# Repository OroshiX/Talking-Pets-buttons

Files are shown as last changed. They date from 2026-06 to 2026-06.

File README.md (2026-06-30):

# Talking Pet Buttons - écoute audio portable

Ce projet transforme un Arduino GIGA R1 WiFi en boîtier d'écoute pour boutons
enregistrables indépendants. Les boutons ne sont pas modifiés : le GIGA écoute
leur son avec un micro analogique, reconnaît chaque bouton par empreinte audio,
journalise les appuis sur une clé USB et envoie une notification `ntfy` via le
hotspot Android.

## Principe

```mermaid
flowchart LR
  A["Bouton enregistrable"] --> B["Son dans la pièce"]
  B --> C["Micro analogique A0"]
  C --> D["Arduino GIGA"]
  D --> E["Fingerprint audio"]
  E --> F["Log CSV sur clé USB"]
  E --> G["ntfy via hotspot Android"]
```

La V1 vise 6 à 8 boutons sur 2 tiles de yoga. Chaque bouton est placé dans un
support imprimé en 3D de type cylindre creux : une petite protubérance
intérieure suspendue porte le bouton, la zone sous le haut-parleur reste
dégagée, et les évents latéraux orientent le son vers le micro.

## Contenu du projet

- `src/main.cpp` : firmware PlatformIO pour Arduino GIGA R1 WiFi.
- `usb/config/` : exemples de fichiers à copier sur la clé USB.
- `hardware/button-riser.stl` : support 3D prêt pour PrusaSlicer.
- `hardware/button-riser.scad` : source paramétrique OpenSCAD du support.
- `docs/01-mise-en-route.md` : démarrage, firmware, USB, placement et calibration.
- `docs/02-liste-achats.md` : matériel recommandé pour la V1.
- `docs/03-agencement.md` : placement des tiles, du GIGA, du micro et des boutons.
- `docs/04-cablage.md` : câblage minimal du micro et de l'alimentation.
- `docs/05-schemas-branchement.md` : branchements micro, USB, alimentation et flux.
- `docs/06-cle-usb.md` : structure de la clé USB et formats des fichiers.
- `docs/07-calibration.md` : apprentissage des boutons avec les commandes série.
- `docs/08-tests.md` : checklist de validation avant usage quotidien.
- `hardware/01-support-3d.md` : support imprimable et réglages PrusaSlicer.
- `audio/01-audio.md` : notes sur les données audio utilisées par la V1.
- `docs/images/` : schémas SVG exportables/imprimables.

## Matériel V1

- Arduino GIGA R1 WiFi.
- Module micro analogique 3.3 V à gain réglable, type MAX4466.
- Clé USB-A FAT32.
- Batterie externe USB-C ou chargeur USB-C.
- Téléphone Android avec hotspot et application `ntfy`.
- 6 à 8 boutons enregistrables indépendants.
- 2 tiles de yoga emboîtables.
- Supports imprimés en 3D, un par bouton.
- Option : panneau de calibration avec 3 boutons NO et 6 LEDs binaires.

## Démarrage rapide

1. Copier `usb/config/buttons.csv`, `usb/config/settings.ini` et un
   `secrets.ini` basé sur `usb/config/secrets.example.ini` à la racine d'une
   clé USB FAT32, en gardant les dossiers.
2. Brancher le micro :
   - `VCC` vers `3V3` ;
   - `GND` vers `GND` ;
   - `OUT` vers `A0`.
3. Brancher la clé USB dans le port USB-A du GIGA.
4. Alimenter le GIGA en USB-C.
5. Compiler et téléverser avec PlatformIO.
6. Ouvrir le moniteur série à `115200` bauds, ou utiliser
   `pio device monitor -b 115200`.
7. Lancer `cal A1 12`, puis presser le bouton A1 12 fois.
8. Répéter pour chaque bouton.
9. Lancer `testntfy`, puis vérifier l'application Android.

## Commandes série

```text
help              affiche les commandes
list              affiche les boutons et templates chargés
status            affiche USB, Wi-Fi, heure, bruit, sélection et calibration
usb               monte ou remonte la clé USB maintenant
reload            recharge la config et les templates depuis la clé USB
select N          règle la sélection du panneau ; 0 éteint les LEDs binaires
ledtest N         affiche une valeur brute 0..63 sur les LEDs binaires
wifi              connecte le GIGA au Wi-Fi configuré maintenant
ntp               synchronise l'heure NTP maintenant
cal A1 [12]       apprend les prochains appuis pour le slot A1
cancel            annule une calibration active
testntfy          envoie une notification de test
```

Le panneau de calibration optionnel utilise `D22` pour `CAL`, `D23` pour `+`,
`D24` pour `-`, et `D25` à `D30` pour les 6 LEDs binaires. L'état `000000`
signifie qu'aucun bouton animal n'est sélectionné.

## Important

- Le GIGA ne fait pas de reconnaissance vocale générale. Il compare des sons de
  boutons déjà appris.
- Si tu réenregistres le message d'un bouton, il faut refaire sa calibration.
- Si tu changes fortement la position du micro ou des boutons, refais au moins
  un test de précision.
- Les notifications sont mises en attente dans `/queue/ntfy-pending.jsonl` si le
  hotspot est indisponible.

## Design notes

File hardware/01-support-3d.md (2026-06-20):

# Support 3D pour bouton

`button-riser.stl` est le fichier prêt à ouvrir dans PrusaSlicer. Les unités
sont en millimètres.

`button-riser.scad` est la source paramétrique OpenSCAD si tu veux changer le
diamètre du bouton ou la hauteur du support. Le design est un cylindre creux :
le bouton repose sur une petite protubérance intérieure suspendue, et la chambre
centrale reste dégagée sous le haut-parleur.

`generate_button_riser_stl.py` génère le STL sans dépendance externe :

```sh
python3 hardware/generate_button_riser_stl.py
```

Orientation :

- la petite flèche en relief pointe vers le micro ;
- le grand évent latéral doit aussi être orienté vers le micro ;
- le bouton se pose par-dessus, sur la petite protubérance intérieure ;
- imprimer à plat, sans rotation.

Réglages de départ PrusaSlicer :

- PLA ou PETG ;
- hauteur de couche 0,20 mm ;
- 3 périmètres ;
- 15 à 20% d'infill ;
- supports désactivés pour un premier essai.

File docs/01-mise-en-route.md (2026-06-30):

# Mise en route

## 1. Préparer le firmware

Dans CLion, VS Code ou un terminal PlatformIO :

```sh
pio run
pio run --target upload
```

La cible attendue est `giga_r1_m7` dans `platformio.ini`.

Pour éviter de retaper la vitesse du moniteur série à chaque fois, garder aussi
la ligne suivante dans `platformio.ini` :

```ini
monitor_speed = 115200
```

Ouvrir ensuite le moniteur série à `115200` bauds. Au démarrage, le GIGA affiche
la liste des commandes :

```text
help
list
status
usb
reload
select 0
ledtest 63
wifi
ntp
cal A1 12
cancel
testntfy
```

Ces commandes sont à taper dans le moniteur série connecté au GIGA, pas dans le
terminal de l'ordinateur. Elles sont l'interface de diagnostic et de calibration
du firmware.

`115200` bauds est la vitesse de communication entre l'ordinateur et le GIGA pour
ce moniteur série. Dans Arduino IDE, choisir `115200 baud` dans le menu du
moniteur série. Avec PlatformIO en terminal, utiliser :

```sh
pio device monitor -b 115200
```

## 2. Préparer la clé USB

Formater une clé USB-A en FAT32, puis copier la structure suivante :

```text
/config/buttons.csv
/config/settings.ini
/config/secrets.ini
/templates/
/logs/
/queue/
/captures/
```

Les exemples du dépôt sont dans `usb/config/`.

`secrets.ini` n'est pas versionné, car il contient le mot de passe hotspot et le
topic `ntfy`.

## 3. Brancher le micro

```text
Module micro analogique        Arduino GIGA

VCC  ------------------------>  3V3
GND  ------------------------>  GND
OUT  ------------------------>  A0
```

Utiliser `3V3`, pas `5V`. Garder les fils du micro courts : 30 cm maximum est un
bon objectif.

## 4. Placer le setup

Lire `docs/03-agencement.md`, puis installer :

- le GIGA derrière les tiles, hors zone de pattes ;
- le micro à 25-35 cm de haut, pointé vers le centre des boutons ;
- les boutons posés dans leurs supports 3D, avec l'évent le plus large orienté
  vers le micro.

## 5. Calibrer les boutons

Deux méthodes sont possibles : les commandes série ci-dessous, ou le panneau
physique décrit dans `docs/07-calibration.md`.

Pour chaque slot :

```text
cal A1 12
```

Presser ensuite le bouton A1 12 fois, depuis sa vraie position sur la tile.

Répéter :

```text
cal A2 12
cal A3 12
cal A4 12
cal B1 12
cal B2 12
```

Le GIGA crée les fichiers :

```text
/templates/A1.tpl
/templates/A2.tpl
...
```

## 6. Tester

Commandes utiles :

```text
status
list
usb
select 0
ledtest 63
wifi
ntp
testntfy
```

Puis presser chaque bouton 20 fois en conditions réelles. La checklist complète
est dans `docs/08-tests.md`.

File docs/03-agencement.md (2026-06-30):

# Agencement physique

## Vue de dessus

Agencement audio

```text
Mur / zone hors passage animal

        [Boîtier GIGA]
             |
        mât micro 25-35 cm haut
             v
        micro pointe vers centre des boutons

+--------------------+--------------------+
| Tile A             | Tile B             |
|                    |                    |
|  A1      A2        |  B1      B2        |
|                    |                    |
|  A3      A4        |  B3      B4        |
|                    |                    |
+--------------------+--------------------+

Animal arrive plutôt par le bas / côté ouvert.
```

## Positions recommandées

- Boîtier GIGA : derrière les tiles, hors zone de pattes.
- Micro : environ 20 cm derrière le bord arrière des tiles.
- Hauteur micro : 25 à 35 cm au-dessus du sol.
- Orientation micro : pointe vers le centre géométrique des boutons.
- Distance micro-boutons : 35 à 80 cm si possible, moins de 1 m en V1.
- Boutons : 8 à 12 cm d'espace entre eux.

## Orientation des boutons

Chaque bouton doit être posé dans un support imprimé. Il repose sur une petite
protubérance intérieure du cylindre ; cette tablette ne descend pas jusqu'en
bas, donc la chambre centrale reste ouverte sous le haut-parleur. L'évent le
plus large du support est orienté vers le micro.

```text
Micro
  ^
  |
  |       évent large du support
  |              ^
  |              |
+---+        +--------+
| A1|        |   A2   |
+---+        +--------+
```

## Routine de voyage

Pour déplacer le setup :

1. laisser les boutons dans leurs supports ;
2. empiler les tiles ;
3. garder le micro fixe au boîtier ou à un petit mât pliable ;
4. brancher le GIGA à une batterie externe ;
5. activer le hotspot Android ;
6. si tu vérifies depuis l'ordinateur, lancer `wifi` puis `ntp`, ou attendre
   `Wi-Fi connected` et `NTP synced` si `auto_ntp=true`.

Si le placement change beaucoup, lancer au minimum un test de 5 pressions par
bouton. Si la confiance baisse nettement, refaire la calibration.

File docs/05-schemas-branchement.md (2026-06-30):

# Schémas de branchement et flux

## Vue générale

Schéma de branchement global

Ce schéma montre les branchements réels à faire. Le point important : les piles
des boutons enregistrables restent dans les boutons. Elles ne servent pas à
alimenter l'Arduino. Le GIGA est alimenté séparément par USB-C, idéalement avec
une batterie externe ou un chargeur USB-C stable.

```text
Batterie externe USB-C 5 V
        |
        v
Arduino GIGA R1 WiFi
   | USB-A  -> clé USB FAT32
   | 3V3    -> VCC du micro MAX4466
   | A0     -> OUT / AO du micro MAX4466
   | GND    -> GND du micro MAX4466
   | Wi-Fi  -> hotspot Android -> ntfy
   | D22    -> bouton CAL vers GND
   | D23    -> bouton + vers GND
   | D24    -> bouton - vers GND
   | D25-D30 -> 6 LEDs binaires avec résistances 1 kΩ

Boutons enregistrables
   | piles internes
   | aucun fil vers le GIGA
   v
son capté par le micro
```

Agencement audio

```text
Téléphone Android hotspot ))) Wi-Fi ))) Arduino GIGA ))) HTTPS ))) ntfy
                                             |
USB-C power bank ----------------------------+
                                             |
Clé USB FAT32 ---- USB-A GIGA ---------------+
                                             |
Micro analogique ---- A0 / 3V3 / GND --------+
```

Le GIGA ne touche pas aux boutons. Les boutons restent indépendants, avec leur
pile et leur propre message enregistré. La seule liaison entre les boutons et le
GIGA est acoustique : le bouton joue son message, puis le micro le capte.

## Branchement micro

Branchement micro

```text
Module micro analogique        Arduino GIGA

VCC  ------------------------>  3V3
GND  ------------------------>  GND
OUT  ------------------------>  A0
```

Règles :

- alimenter le micro en `3V3` ;
- ne jamais envoyer de `5V` sur `A0` ;
- garder les fils courts ;
- régler le gain pour qu'un bouton fort ne sature pas le signal.

Le micro n'a pas besoin de pile séparée : il est alimenté par le `3V3` du GIGA.

## Panneau de calibration optionnel

Le panneau de calibration permet de choisir et calibrer un bouton animal sans
ordinateur. Les commandes série restent disponibles.

```text
Boutons électriques NO         Arduino GIGA

CAL borne 1 ----------------->  D22
CAL borne 2 ----------------->  GND

+ borne 1 ------------------->  D23
+ borne 2 ------------------->  GND

- borne 1 ------------------->  D24
- borne 2 ------------------->  GND
```

Ces boutons utilisent `INPUT_PULLUP`, donc aucune résistance externe n'est
nécessaire pour eux.

```text
LEDs binaires                 Arduino GIGA

bit 1  LED + résistance 1 kΩ  D25
bit 2  LED + résistance 1 kΩ  D26
bit 4  LED + résistance 1 kΩ  D27
bit 8  LED + résistance 1 kΩ  D28
bit 16 LED + résistance 1 kΩ  D29
bit 32 LED + résistance 1 kΩ  D30
```

Ordre de lecture recommandé de gauche à droite : `32 16 8 4 2 1`, donc
`D30 D29 D28 D27 D26 D25`. L'état `000000` signifie qu'aucun bouton animal n'est
sélectionné.

## Support audio du bouton

Support bouton

Objectif : que le bouton repose dans un cylindre creux, sur une petite
protubérance intérieure suspendue, pendant que la zone sous le haut-parleur
reste ouverte au lieu d'être absorbée par la tile de yoga.

Le support recommandé :

- parois droites ;
- cylindre creux simple, sans plancher central ;
- protubérance intérieure à 7 mm de haut environ ;
- protubérance de quelques millimètres d'épaisseur et de profondeur ;
- cette protubérance ne descend pas jusqu'en bas du cylindre ;
- chambre centrale ouverte sous le haut-parleur ;
- 3 à 4 évents latéraux connectés à cette chambre d'air ;
- un évent plus large orienté vers le micro ;
- Velcro ou patins caoutchouc dessous.

Le fichier prêt pour PrusaSlicer est :

```text
hardware/button-riser.stl
```

La source modifiable reste :

```text
hardware/button-riser.scad
```

## Flux logiciel

```mermaid
flowchart LR
  A["Bouton pressé"] --> B["Son capté par A0"]
  B --> C["Seuil adaptatif + pré-roll"]
  C --> D["Capture 1,5 s"]
  D --> E["Fingerprint audio"]
  E --> F["Comparaison templates"]
  F --> G{"Confiance >= 0,75 ?"}
  G -->|oui| H["Log CSV + ntfy"]
  G -->|non| I["Log unknown"]
```

Si le Wi-Fi ou le hotspot n'est pas disponible, l'événement reconnu est ajouté à :

```text
/queue/ntfy-pending.jsonl
```

Le GIGA renvoie cette file au retour du Wi-Fi si `auto_queue_flush=true`. En
mode diagnostic, garder `auto_queue_flush=false` et tester d'abord `wifi`, `ntp`,
puis `testntfy`.

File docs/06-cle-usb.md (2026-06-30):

# Clé USB

## Structure

```text
/config/buttons.csv
/config/settings.ini
/config/secrets.ini
/templates/A1.tpl
/templates/A2.tpl
/logs/YYYY-MM-DD.csv
/logs/unsynced.csv
/queue/ntfy-pending.jsonl
/captures/
```

Le firmware crée les dossiers manquants au démarrage, mais il est plus simple de
copier la structure du dossier `usb/` du dépôt.

## `/config/buttons.csv`

```csv
slot,word,ntfy_label
A1,manger,Manger
A2,eau,Eau
A3,jouer,Jouer
A4,dehors,Dehors
B1,dedans,Dedans
B2,calin,Câlin
```

- `slot` : position physique sur les tiles.
- `word` : identifiant court dans les logs.
- `ntfy_label` : texte humain dans les notifications.

## `/config/secrets.ini`

Créer ce fichier à partir de `secrets.example.ini`.

```ini
wifi_ssid=NomDuHotspot
wifi_pass=MotDePasseHotspot
ntfy_host=ntfy.sh
ntfy_topic=topic-prive-long
ntfy_token=
ntfy_tls=true
timezone_offset_minutes=120
```

Utiliser un topic `ntfy` long et difficile à deviner. Ne pas versionner
`secrets.ini`.

## `/config/settings.ini`

```ini
confidence_threshold=0.75
match_distance_at_zero=0.12
min_trigger_abs=650
trigger_multiplier=4.0
capture_ms=1500
cooldown_ms=800
calibration_samples=12
auto_ntp=false
auto_queue_flush=false
```

Ces valeurs sont rechargeables avec la commande série :

```text
reload
```

Si `status` affiche `USB=missing`, la commande série `usb` tente de remonter la
clé sans recharger toute la configuration. `reload` tente aussi de remonter la
clé, puis recharge `buttons.csv`, `settings.ini`, `secrets.ini` et les templates.

`auto_ntp=false` empêche la synchronisation NTP automatique au démarrage. C'est
le mode recommandé tant que la connexion réseau est en diagnostic : le GIGA
reste disponible dans le moniteur série, puis tu peux lancer `wifi` et `ntp`
manuellement. Une fois le Wi-Fi/NTP validé, tu peux passer à `auto_ntp=true`.

`auto_queue_flush=false` empêche l'envoi automatique de la file
`/queue/ntfy-pending.jsonl` toutes les 30 secondes. Les notifications directes
restent testables avec `testntfy`.

## Templates

Les fichiers `/templates/*.tpl` sont générés par le firmware. Exemple :

```text
TPB_TEMPLATE_V1
slot=A1
word=manger
samples=12
features=0.0612,0.0588,...
```

Ils sont propres à tes boutons, à tes enregistrements et au placement micro.

## Logs

```csv
timestamp,slot,word,confidence,duration_ms,noise_floor,notified
2026-06-16T14:32:08+02:00,A1,manger,0.86,1500,142,true
```

Si l'heure NTP n'est pas encore synchronisée, les lignes vont dans :

```text
/logs/unsynced.csv
```

## File de notifications

Si le Wi-Fi échoue :

```text
/queue/ntfy-pending.jsonl
```

Si `auto_queue_flush=true`, le firmware tente de vider cette file toutes les 30
secondes quand le Wi-Fi est disponible.

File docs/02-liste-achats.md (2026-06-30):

# Liste d'achat France / UE

Liste vérifiée pour un achat depuis la France le 2026-06-20. Les liens sont des
exemples de composants compatibles, avec prix affichés en euros quand la page le
permet. Il n'est pas obligatoire d'acheter exactement ces références si les
caractéristiques restent les mêmes.

Avant de commander, vérifier :

- prix TTC en euros ;
- disponibilité réelle ;
- livraison vers la France métropolitaine ;
- frais de port ;
- délai annoncé.

## Électronique principale

- [x] Arduino GIGA R1 WiFi, recommandé depuis la boutique Arduino officielle :
  https://store.arduino.cc/products/giga-r1-wifi
  - prix constaté : 77,90 € TTC ;
  - livraison France indiquée sur la boutique Arduino ;
  - la page affiche aussi la livraison gratuite vers la France au-dessus de
    50 €.
- [ ] Module micro analogique à gain réglable MAX4466, compatible 3.3 V :
  https://www.lextronic.fr/module-microphone-amplifie-max4466-80057.html
  - prix constaté : 8,95 € TTC ;
  - disponibilité constatée : disponible ;
  - frais de port constatés : à partir de 7,90 € ;
  - référence Lextronic : `ADA1063`.
- [ ] Alternative micro si Lextronic est en rupture :
  https://www.adafruit.com/product/1063
  - ne pas l'utiliser comme premier choix depuis la France, car le prix est en
    dollars ;
  - préférer un distributeur France / UE listé par Adafruit, par exemple
    Lextronic, GoTronic ou Letmeknow.
- [ ] Clé USB-A courte, FAT32, 8 à 32 Go :
  - ordre de prix France : 5 à 12 € ;
  - acheter chez Boulanger, LDLC, Amazon.fr, Fnac/Darty ou en grande surface ;
  - choisir un modèle court pour éviter de forcer sur le port USB-A du GIGA.
- [ ] Batterie externe USB-C 5 V, ou chargeur USB-C stable :
  - ordre de prix France : 20 à 40 € pour une batterie 5 000 à 10 000 mAh ;
  - Boulanger affiche de nombreuses batteries externes USB-C en euros ;
  - une sortie 5 V / 2 A suffit largement pour la V1.
- [ ] Câble USB-C court pour alimenter le GIGA :
  - ordre de prix France : 5 à 15 € ;
  - prendre un câble charge + données si possible, même si l'alimentation seule
    suffit en usage quotidien.

## Installation physique

- [ ] 6 à 8 boutons enregistrables indépendants :
  - ordre de prix France : souvent 20 à 45 € le lot de 4, selon le diamètre et
    la qualité audio ;
  - chercher `boutons enregistrables chien chat` ou `boutons enregistrables
    animaux` sur Amazon.fr, Cdiscount, Etsy ou boutiques d'éducation animale ;
  - vérifier que chaque bouton est autonome, avec pile et message enregistrable.
- [ ] 2 tiles de yoga / tapis mousse emboîtables :
  - ordre de prix France : 15 à 35 € selon surface et épaisseur ;
  - chercher `dalles mousse emboîtables`, `tapis puzzle mousse` ou `tapis yoga
    puzzle` ;
  - préférer une mousse stable et pas trop molle, pour ne pas absorber trop de
    son.
- [ ] Fil Dupont femelle-femelle ou câble 3 conducteurs pour le micro :
  - ordre de prix France / UE : 3 à 8 € ;
  - disponible chez GoTronic, Lextronic, Amazon.fr ou kits Arduino génériques.
- [ ] Petite boîte pour le GIGA :
  - ordre de prix France : 5 à 15 € ;
  - une boîte plastique basse suffit, avec ouvertures pour USB-C, USB-A et fils
    du micro.
- [ ] Petit mât ou support orientable pour le micro :
  - ordre de prix France : 5 à 20 € ;
  - une tige imprimée en 3D, un mini trépied, ou un col de cygne léger convient.
- [ ] Velcro adhésif, patins caoutchouc, double-face mousse fine :
  - ordre de prix France : 5 à 15 € au total ;
  - disponible en magasin de bricolage, supermarché ou Amazon.fr.
- [ ] Filament PLA/PETG pour les supports 3D :
  - ordre de prix France / UE : 18 à 30 € la bobine de 1 kg ;
  - PLA recommandé pour un premier essai, PETG si les supports doivent mieux
    résister à la chaleur ou aux manipulations.

## Option panneau de calibration

- [ ] 3 boutons poussoirs normalement ouverts, pour `CAL`, `+` et `-` :
  - ordre de prix France / UE : 3 à 10 € le lot ;
  - disponible chez GoTronic, Lextronic ou dans un kit de composants Arduino.
- [ ] 6 LEDs 3 mm ou 5 mm, couleur au choix :
  - ordre de prix France / UE : 2 à 6 € le lot.
- [ ] 6 résistances `1 kΩ`, une par LED :
  - ordre de prix France / UE : 1 à 3 € le lot.
- [ ] Fils Dupont ou câble fin pour relier le panneau au GIGA.
- [ ] Plaque de prototypage, petit panneau percé ou boîtier imprimé.

Les 3 boutons électriques n'ont pas besoin de résistances externes, car le GIGA
utilise `INPUT_PULLUP`. Les 6 LEDs ont besoin de résistances, car elles sont
pilotées par des sorties GPIO.

## Application Android

- Application `ntfy`.
- Hotspot Android activé pendant les sessions d'usage.
- Topic privé long et non devinable dans `secrets.ini`.

## Fournisseurs conseillés

- Arduino Store :
  https://store.arduino.cc/products/giga-r1-wifi
  - meilleur choix pour le GIGA si le prix officiel reste correct.
- Lextronic :
  https://www.lextronic.fr/module-microphone-amplifie-max4466-80057.html
  - bon choix pour le MAX4466 en France, prix TTC en euros.
- GoTronic :
  https://www.gotronic.fr/
  - bon fournisseur français pour câbles, fils Dupont, boîtiers, connectique,
    modules et filament.
- Boulanger :
  https://www.boulanger.com/resultats?tr=batterie+externe+usb+c
  - utile pour batterie externe USB-C, chargeur et câble USB-C.
- Amazon.fr / Cdiscount / Fnac-Darty :
  - utiles pour boutons enregistrables, clé USB courte, Velcro, patins et tapis
    mousse ;
  - vérifier le vendeur réel et éviter les fiches sans dimensions claires.

## À éviter

- Micro USB : le firmware V1 attend un signal analogique sur `A0`.
- Micro électret nu sans module d'amplification : le signal sera trop faible.
- Alimentation du micro en 5 V si sa sortie peut dépasser 3.3 V.
- Page produit en dollars hors UE quand un équivalent France / UE existe.

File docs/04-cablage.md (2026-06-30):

# Câblage

La V1 audio-only n'utilise plus de câblage bouton par bouton. Les boutons
enregistrables restent autonomes.

Le seul câblage obligatoire est celui du micro analogique :

```text
Module micro analogique        Arduino GIGA

VCC  ------------------------>  3V3
GND  ------------------------>  GND
OUT  ------------------------>  A0
```

Le reste :

```text
Clé USB FAT32  ----> USB-A du GIGA
Alimentation   ----> USB-C du GIGA
Hotspot Android ))) Wi-Fi ))) GIGA
```

## Panneau de calibration optionnel

Le panneau permet de sélectionner et calibrer les boutons animaux sans ordinateur.
Il n'est pas obligatoire : les commandes série restent disponibles.

Boutons électriques normalement ouverts :

```text
Bouton CAL  ----> D22 et GND
Bouton +    ----> D23 et GND
Bouton -    ----> D24 et GND
```

Ces 3 boutons n'ont pas besoin de résistances externes. Le firmware configure les
pins en `INPUT_PULLUP`, donc le bouton relie simplement la pin à `GND` quand on
appuie.

LEDs binaires :

```text
LED bit 1   ----> D25 -> résistance 1 kΩ -> LED -> GND
LED bit 2   ----> D26 -> résistance 1 kΩ -> LED -> GND
LED bit 4   ----> D27 -> résistance 1 kΩ -> LED -> GND
LED bit 8   ----> D28 -> résistance 1 kΩ -> LED -> GND
LED bit 16  ----> D29 -> résistance 1 kΩ -> LED -> GND
LED bit 32  ----> D30 -> résistance 1 kΩ -> LED -> GND
```

Chaque LED a besoin de sa propre résistance, car une LED est une sortie pilotée
par l'Arduino. Les pull-ups internes ne protègent pas les LEDs.

Ordre visuel recommandé de gauche à droite :

```text
32 16 8 4 2 1
D30 D29 D28 D27 D26 D25
```

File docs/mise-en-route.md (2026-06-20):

# Mise en route

## 1. Préparer le firmware

Dans CLion, VS Code ou un terminal PlatformIO :

```sh
pio run
pio run --target upload
```

La cible attendue est `giga_r1_m7` dans `platformio.ini`.

Ouvrir ensuite le moniteur série à `115200` bauds. Au démarrage, le GIGA affiche
la liste des commandes :

```text
help
list
status
reload
cal A1 12
cancel
testntfy
```

## 2. Préparer la clé USB

Formater une clé USB-A en FAT32, puis copier la structure suivante :

```text
/config/buttons.csv
/config/settings.ini
/config/secrets.ini
/templates/
/logs/
/queue/
/captures/
```

Les exemples du dépôt sont dans `usb/config/`.

`secrets.ini` n'est pas versionné, car il contient le mot de passe hotspot et le
topic `ntfy`.

## 3. Brancher le micro

```text
Module micro analogique        Arduino GIGA

VCC  ------------------------>  3V3
GND  ------------------------>  GND
OUT  ------------------------>  A0
```

Utiliser `3V3`, pas `5V`. Garder les fils du micro courts : 30 cm maximum est un
bon objectif.

## 4. Placer le setup

Lire `docs/agencement.md`, puis installer :

- le GIGA derrière les tiles, hors zone de pattes ;
- le micro à 25-35 cm de haut, pointé vers le centre des boutons ;
- les boutons posés dans leurs supports 3D, avec l'évent le plus large orienté
  vers le micro.

## 5. Calibrer les boutons

Pour chaque slot :

```text
cal A1 12
```

Presser ensuite le bouton A1 12 fois, depuis sa vraie position sur la tile.

Répéter :

```text
cal A2 12
cal A3 12
cal A4 12
cal B1 12
cal B2 12
```

Le GIGA crée les fichiers :

```text
/templates/A1.tpl
/templates/A2.tpl
...
```

## 6. Tester

Commandes utiles :

```text
status
list
testntfy
```

Puis presser chaque bouton 20 fois en conditions réelles. La checklist complète
est dans `docs/tests.md`.

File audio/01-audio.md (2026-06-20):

# Audio

L'ancien projet utilisait des fichiers WAV joués par l'Arduino. La V1 actuelle
fait l'inverse : les sons viennent des boutons enregistrables, et le GIGA les
écoute.

Les données audio utiles sont maintenant :

- les templates appris dans `/templates/*.tpl` sur la clé USB ;
- les logs de reconnaissance dans `/logs/*.csv` ;
- la file de notifications dans `/queue/ntfy-pending.jsonl`.

Il n'y a donc plus de fichiers WAV à copier pour le firmware actuel.

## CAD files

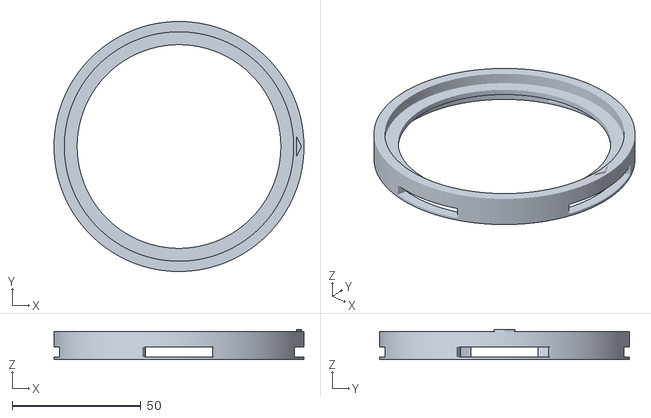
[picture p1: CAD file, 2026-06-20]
hardware/button-riser.stl
97.0 x 97.0 x 11.8

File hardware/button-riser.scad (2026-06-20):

// Talking Pet Buttons - parametric cylindrical sound riser
// Open in OpenSCAD, adjust button_diameter and export STL.

$fn = 96;

button_diameter = 88;       // mm, measure the bottom of the recordable button
inner_clearance = 1.0;      // mm
outer_wall = 4.0;           // mm, simple cylindrical wall thickness
total_height = 11.0;        // mm, full height of the support cylinder
ledge_top_height = 7.0;     // mm, top of the small inner shelf where the button rests
ledge_thickness = 2.0;      // mm, vertical thickness of the shelf
ledge_depth = 5.0;          // mm, how far the shelf protrudes inward
side_vent_width = 28.0;     // mm
side_vent_height = 4.0;     // mm
side_vent_bottom = 1.0;     // mm, keep vents below the inner shelf

inner_diameter = button_diameter + inner_clearance;
outer_diameter = inner_diameter + outer_wall * 2;
inner_radius = inner_diameter / 2;
outer_radius = outer_diameter / 2;
ledge_inner_radius = inner_radius - ledge_depth;
ledge_bottom_height = ledge_top_height - ledge_thickness;

module cylinder_wall() {
  difference() {
    cylinder(d = outer_diameter, h = total_height);
    translate([0, 0, -0.1])
      cylinder(d = inner_diameter, h = total_height + 0.2);
  }
}

module inner_ledge() {
  translate([0, 0, ledge_bottom_height])
    difference() {
      cylinder(r = inner_radius, h = ledge_thickness);
      translate([0, 0, -0.1])
        cylinder(r = ledge_inner_radius, h = ledge_thickness + 0.2);
    }
}

module radial_side_vent(angle, width, height) {
  rotate([0, 0, angle])
    translate([(inner_radius + outer_radius) / 2, 0, side_vent_bottom + height / 2])
      cube([outer_radius - inner_radius + 4, width, height], center = true);
}

difference() {
  union() {
    // Main body: a simple hollow cylinder.
    cylinder_wall();

    // Small suspended inner shelf. It supports the button but does not continue
    // down to the bottom, leaving an air chamber below it.
    inner_ledge();
  }

  // Radial vents through the cylindrical wall, below the inner shelf.
  radial_side_vent(0, side_vent_width * 1.35, side_vent_height);
  radial_side_vent(90, side_vent_width, side_vent_height);
  radial_side_vent(180, side_vent_width, side_vent_height);
  radial_side_vent(270, side_vent_width, side_vent_height);
}

// Orientation marker: this arrow points toward the microphone.
translate([outer_radius - 5, 0, total_height + 0.4])
  linear_extrude(0.8)
    polygon(points = [[-4, -4], [5, 0], [-4, 4]]);

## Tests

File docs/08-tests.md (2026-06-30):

# Plan de tests

## 0. Préparer le banc de test

Les commandes comme `status`, `list`, `cal A1 12` ou `testntfy` ne sont pas des
commandes à lancer dans le terminal de l'ordinateur. Ce sont des commandes série
à envoyer au firmware qui tourne sur l'Arduino GIGA.

Pour les lancer :

1. brancher le GIGA à l'ordinateur en USB-C ;
2. brancher la clé USB FAT32 sur le port USB-A du GIGA ;
3. brancher le micro MAX4466 au GIGA : `VCC` vers `3V3`, `OUT` vers `A0`,
   `GND` vers `GND` ;
4. brancher le panneau de calibration si tu veux tester la calibration sans
   ordinateur ;
5. placer les boutons à leur position réelle sur les tiles ;
6. activer le hotspot Android si le test concerne le Wi-Fi, l'heure ou `ntfy` ;
7. ouvrir le moniteur série PlatformIO, Arduino IDE, CLion ou VS Code à
   `115200` bauds ;
8. taper la commande dans le champ d'envoi du moniteur série, puis appuyer sur
   Entrée.

Si le GIGA est seulement branché à une batterie externe, il fonctionne, mais tu
ne peux pas taper `status` sans liaison série avec l'ordinateur. Pour les tests,
le plus simple est donc d'alimenter le GIGA depuis l'ordinateur en USB-C, puis de
passer sur batterie externe seulement pour le test de portabilité.

`115200` bauds est la vitesse de communication de cette console série. Dans
PlatformIO, `monitor_speed = 115200` dans `platformio.ini` règle cette vitesse
par défaut ; en terminal, `pio device monitor -b 115200` ouvre le moniteur à la
bonne vitesse.

La commande `status` affiche une ligne de diagnostic du firmware, par exemple :

```text
USB=mounted WiFi=connected time=synced noise=142 threshold=650 selected=A1 selected_no=1 calibration=active progress=3/12 auto_ntp=off auto_queue=off
```

Signification :

- `USB=mounted` : la clé USB est détectée et montée ;
- `WiFi=connected` : le GIGA est connecté au hotspot Android ;
- `time=synced` : l'heure a été récupérée par NTP ;
- `noise=142` : niveau de bruit de fond mesuré par le micro ;
- `threshold=650` : seuil au-dessus duquel un son déclenche une capture ;
- `selected=A1 selected_no=1` : bouton animal actuellement sélectionné ;
- `calibration=active progress=3/12` : calibration en cours, 3 exemples captés
  sur 12 ;
- `auto_ntp=off` : le firmware ne lance pas NTP automatiquement au démarrage ;
- `auto_queue=off` : le firmware ne vide pas automatiquement la file `ntfy`.

## 0.1. Test diagnostic Wi-Fi/NTP

Si le GIGA ne répond plus aux commandes série dès que le Wi-Fi se connecte,
garder ces lignes dans `/config/settings.ini` :

```ini
auto_ntp=false
auto_queue_flush=false
```

Après un reset, tester dans cet ordre :

```text
status
wifi
status
usb
status
ntp
status
```

Interprétation :

- si `status` répond après le reset, la liaison série fonctionne ;
- si `USB=missing` apparaît après le Wi-Fi, lancer `usb` pour tenter un remontage
  manuel de la clé ;
- si la carte clignote rouge ou ne répond plus pendant `wifi`, noter la dernière
  ligne affichée entre `Wi-Fi: begin`, `Wi-Fi: begin returned`, `Wi-Fi: status
  after wait` et `Wi-Fi: reading local IP` ;
- si `wifi` fonctionne mais que la carte clignote rouge ou ne répond plus
  pendant `ntp`, noter la dernière ligne affichée entre `NTP: starting UDP`,
  `NTP: sending request`, `NTP: beginPacket` et `NTP: endPacket` ;
- une fois le diagnostic stable, repasser à `auto_ntp=true` seulement si le test
  `ntp` manuel ne bloque pas la carte.

## 1. Test micro

Depuis le moniteur série, envoyer :

```text
status
```

Vérifier :

- `USB=mounted` ;
- `noise` stable au repos ;
- `threshold` supérieur au bruit de fond ;
- un bouton pressé déclenche `Audio event started`.

Si rien ne déclenche :

- augmenter le gain du micro ;
- rapprocher le micro ;
- baisser `min_trigger_abs` dans `/config/settings.ini`.

Si tout déclenche :

- baisser le gain du micro ;
- augmenter `trigger_multiplier` ;
- éloigner le micro de la zone de passage.

## 2. Test acoustique du support

Comparer chaque bouton dans deux configurations :

1. posé directement sur la tile ;
2. posé dans le support imprimé.

Garder le support si :

- le son est plus clair à l'oreille ;
- la confiance moyenne augmente ;
- les faux positifs ne montent pas.

## 3. Calibration

Pour chaque bouton :

```text
cal A1 12
```

Règles :

- presser depuis la vraie position finale ;
- laisser le son finir entre deux pressions ;
- refaire la calibration si le message du bouton est réenregistré ;
- refaire la calibration si le micro change fortement de place.

Test du panneau physique :

- envoyer `ledtest 1`, `ledtest 2`, `ledtest 4`, `ledtest 8`, `ledtest 16`,
  puis `ledtest 32` et vérifier que chaque LED s'allume seule ;
- envoyer `ledtest 63` et vérifier que les 6 LEDs s'allument ;
- envoyer `select 0` depuis le moniteur série et vérifier que les LEDs
  s'éteignent ;
- envoyer `select 1`, `select 2`, puis `select 3` et vérifier respectivement
  `000001`, `000010`, puis `000011` ;
- utiliser `+` et `-` pour parcourir `0..N` sans boucle automatique ;
- vérifier que `0` éteint les 6 LEDs binaires ;
- vérifier que `000001` correspond au bouton n°1 de `buttons.csv` ;
- faire un appui long sur `CAL` à `0` : aucune calibration ne démarre ;
- sélectionner le bouton n°1, puis faire un appui long sur `CAL` ;
- vérifier que la LED intégrée clignote 3 fois puis reste allumée ;
- pendant la calibration, appuyer sur `+` et `-` : la sélection ne doit pas
  changer ;
- après 12 exemples, vérifier que la sélection passe au bouton suivant.

## 4. Précision

Après calibration :

- presser chaque bouton 20 fois ;
- viser au moins 18 reconnaissances correctes sur 20 par bouton ;
- noter les boutons confondus.

Si deux boutons sont confondus :

- enregistrer des mots plus différents ;
- augmenter l'espace entre ces boutons ;
- refaire les templates ;
- baisser `match_distance_at_zero` ou augmenter `confidence_threshold`.

## 5. Faux positifs

Tester :

- voix humaine proche ;
- télévision ou musique ;
- pas autour des tiles ;
- objet posé sur la tile ;
- bouton touché sans déclencher son message.

Attendu : pas de notification. Les événements ambigus peuvent apparaître dans
`/logs/unsynced.csv` ou le log du jour avec `slot=unknown`.

## 6. Portabilité

Séquence :

1. éteindre le GIGA ;
2. déplacer tiles, boutons, micro et boîtier ;
3. rallumer sur batterie externe ;
4. activer le hotspot Android ;
5. si un ordinateur est branché temporairement en USB-C, vérifier `status` ;
6. presser chaque bouton.

Attendu :

- le GIGA retrouve la clé USB ;
- l'heure NTP se synchronise ;
- les logs vont dans `/logs/YYYY-MM-DD.csv` ;
- les notifications arrivent sur Android.

Sans ordinateur branché, ce test se valide surtout par les notifications Android
et par les fichiers de log créés sur la clé USB après extinction propre du GIGA.

## 7. Offline

Séquence :

1. couper le hotspot ;
2. presser deux boutons connus ;
3. vérifier que `/queue/ntfy-pending.jsonl` grossit ;
4. rallumer le hotspot ;
5. attendre 30 secondes.

Attendu : les notifications en attente sont envoyées, puis la file est vide.

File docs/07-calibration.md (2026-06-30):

# Calibration audio

La calibration crée un template moyen pour chaque bouton. Le firmware compare
ensuite chaque nouveau son à ces templates.

## Préparation

Avant de calibrer :

- mettre les boutons à leur place finale ;
- placer le micro à sa hauteur finale ;
- activer le hotspot Android ;
- brancher la clé USB.

Si tu calibres avec les commandes série, ouvrir aussi le moniteur série à
`115200` bauds.

Vérifier :

```text
status
list
select 0
ledtest 63
```

## Calibrer avec le moniteur série

Commande :

```text
cal A1 12
```

Puis presser le bouton A1 12 fois. Attendre que le message audio soit fini avant
la pression suivante.

Le firmware affiche :

```text
Calibration A1: 1/12
Calibration A1: 2/12
...
Calibration complete.
```

Le fichier créé :

```text
/templates/A1.tpl
```

## Calibrer sans ordinateur

Le panneau physique permet de calibrer avec 3 boutons électriques et 6 LEDs :

- `CAL` sur `D22` : appui long pour entrer ou annuler la calibration ;
- `+` sur `D23` : sélectionner le bouton animal suivant ;
- `-` sur `D24` : sélectionner le bouton animal précédent ;
- LEDs `D25` à `D30` : affichage binaire du bouton sélectionné.

Les boutons `CAL`, `+` et `-` sont des boutons normalement ouverts branchés entre
la pin Arduino et `GND`. Ils n'ont pas besoin de résistances externes, car le
firmware utilise les pull-ups internes du GIGA.

Les LEDs s'affichent en binaire direct :

```text
LEDs de gauche à droite : 32 16 8 4 2 1
Pins correspondantes    : D30 D29 D28 D27 D26 D25

000000 = aucun bouton sélectionné
000001 = bouton n°1 dans buttons.csv
000010 = bouton n°2 dans buttons.csv
000011 = bouton n°3 dans buttons.csv
...
111111 = bouton n°63 maximum
```

Procédure :

1. utiliser `+` et `-` pour choisir le bouton animal à calibrer ;
2. vérifier que les LEDs ne sont pas toutes éteintes ;
3. faire un appui long sur `CAL` pendant environ 1 seconde ;
4. attendre les 3 clignotements de la LED intégrée ;
5. presser le bouton animal sélectionné 12 fois, ou le nombre configuré dans
   `calibration_samples` ;
6. à la fin, le template est sauvegardé et la sélection passe automatiquement au
   bouton suivant.

Si les 6 LEDs sont éteintes, la sélection vaut `0`. Dans cet état, un appui long
sur `CAL` ne lance pas de calibration et la LED intégrée clignote rapidement pour
indiquer l'erreur.

Pendant une calibration active, `+` et `-` sont ignorés pour ne pas mélanger les
exemples audio de deux boutons. Pour annuler, refaire un appui long sur `CAL`.

Depuis le moniteur série, la commande `select N` règle la même sélection :

```text
select 0   éteint les 6 LEDs binaires
select 1   sélectionne le bouton n°1
select 2   sélectionne le bouton n°2
```

`select` est ignorée pendant une calibration active.

Pour tester seulement le câblage des LEDs, sans changer la sélection logique,
utiliser `ledtest N` :

```text
ledtest 0    éteint les 6 LEDs
ledtest 1    allume seulement le bit 1, D25
ledtest 2    allume seulement le bit 2, D26
ledtest 4    allume seulement le bit 4, D27
ledtest 8    allume seulement le bit 8, D28
ledtest 16   allume seulement le bit 16, D29
ledtest 32   allume seulement le bit 32, D30
ledtest 63   allume les 6 LEDs
```

Après un `ledtest`, utiliser `select 0` ou `select N` pour revenir à l'affichage
normal de la sélection.

## Calibrer tout le setup V1

```text
cal A1 12
cal A2 12
cal A3 12
cal A4 12
cal B1 12
cal B2 12
```

Pour 8 boutons, ajouter :

```text
cal B3 12
cal B4 12
```

## Quand refaire une calibration

Refaire le template si :

- le message du bouton est réenregistré ;
- le bouton change de support ;
- le micro change fortement de position ;
- la pièce de vacances est beaucoup plus réverbérante ou bruyante ;
- deux boutons sont souvent confondus.

## Réglages utiles

Dans `/config/settings.ini` :

```ini
confidence_threshold=0.75
match_distance_at_zero=0.12
min_trigger_abs=650
trigger_multiplier=4.0
```

Si le GIGA reconnaît trop facilement des bruits :

- monter `confidence_threshold` ;
- monter `trigger_multiplier` ;
- monter `min_trigger_abs`.

Si le GIGA rate des vrais boutons :

- rapprocher le micro ;
- augmenter le gain du micro ;
- baisser légèrement `min_trigger_abs` ;
- refaire la calibration avec le placement final.

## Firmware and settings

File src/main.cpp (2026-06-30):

/*
  Talking Pet Buttons - audio-only portable listener for Arduino GIGA R1 WiFi

  Hardware V1:
  - MAX4466-style analog microphone module powered from 3V3.
  - Microphone OUT connected to A0.
  - USB stick in the GIGA USB-A port for config, templates, logs and queue.
  - Android hotspot for Wi-Fi and ntfy notifications.

  This firmware does not connect to the pet buttons. It learns the sound of
  each independent recordable button and recognizes future presses by comparing
  compact audio fingerprints.
*/

#include <Arduino.h>
#include <Arduino_AdvancedAnalog.h>
#include <Arduino_USBHostMbed5.h>
#include <DigitalOut.h>
#include <FATFileSystem.h>
#include <WiFi.h>

#include <cerrno>
#include <cmath>
#include <cctype>
#include <cstdio>
#include <cstdlib>
#include <cstring>
#include <sys/stat.h>
#include <time.h>

namespace {

constexpr const char *kFirmwareName = "Talking Pet Buttons audio listener";
constexpr const char *kFirmwareVersion = "1.0.0";

constexpr pin_size_t kMicPin = A0;
constexpr uint8_t kCalibrationButtonPin = 22;
constexpr uint8_t kNextButtonPin = 23;
constexpr uint8_t kPreviousButtonPin = 24;
constexpr uint8_t kBinaryLedPins[] = {25, 26, 27, 28, 29, 30};
constexpr uint8_t kBinaryLedCount = sizeof(kBinaryLedPins) / sizeof(kBinaryLedPins[0]);
constexpr uint8_t kMaxPanelSelection = (1U << kBinaryLedCount) - 1U;
constexpr unsigned long kPanelDebounceMs = 30;
constexpr unsigned long kPanelLongPressMs = 1000;
constexpr unsigned long kStatusBlinkMs = 140;
constexpr unsigned long kStatusPulseMs = 80;
constexpr uint8_t kStatusLedOn = LOW;
constexpr uint8_t kStatusLedOff = HIGH;
constexpr uint32_t kSampleRate = 16000;
constexpr size_t kAdcBlockSamples = 128;
constexpr size_t kAdcQueueDepth = 32;
constexpr size_t kMaxAdcBuffersPerLoop = 4;
constexpr size_t kMaxCaptureMs = 1500;
constexpr size_t kMaxCaptureSamples = (kSampleRate * kMaxCaptureMs) / 1000;
constexpr size_t kPreRollSamples = 1024;
constexpr size_t kTriggerHoldSamples = 96;
constexpr size_t kMaxButtons = kMaxPanelSelection;
constexpr size_t kMaxPendingLine = 260;
constexpr uint8_t kEnvelopeBins = 16;
constexpr uint8_t kBandBins = 8;
constexpr uint8_t kFeatureCount = kEnvelopeBins + kBandBins;
constexpr float kPi = 3.14159265358979323846f;

constexpr const char *kButtonsPath = "/usb/config/buttons.csv";
constexpr const char *kSecretsPath = "/usb/config/secrets.ini";
constexpr const char *kSettingsPath = "/usb/config/settings.ini";
constexpr const char *kPendingPath = "/usb/queue/ntfy-pending.jsonl";
constexpr const char *kPendingTmpPath = "/usb/queue/ntfy-pending.tmp";

struct ButtonConfig {
  char slot[8];
  char word[28];
  char ntfyLabel[40];
  bool templateLoaded;
  uint16_t templateSamples;
  float templ[kFeatureCount];
  unsigned long lastRecognizedMs;
};

struct RuntimeSettings {
  char wifiSsid[64];
  char wifiPass[64];
  char ntfyHost[48];
  char ntfyTopic[72];
  char ntfyToken[128];
  char ntpHost[48];
  bool ntfyTls;
  int timezoneOffsetMinutes;
  float confidenceThreshold;
  float matchDistanceAtZero;
  float triggerMultiplier;
  uint16_t minTriggerAbs;
  uint16_t cooldownMs;
  uint16_t captureMs;
  uint8_t calibrationSamples;
  bool autoNtp;
  bool autoQueueFlush;
};

enum class CaptureState {
  Idle,
  Capturing,
};

struct MatchResult {
  int buttonIndex;
  float confidence;
  float distance;
};

struct PanelButtonState {
  uint8_t pin;
  bool stablePressed;
  bool lastReadingPressed;
  unsigned long lastReadingChangedMs;
  unsigned long pressedSinceMs;
  bool longHandled;
};

struct PanelButtonEvents {
  bool shortPressed;
  bool longPressed;
};

ButtonConfig buttons[kMaxButtons];
size_t buttonCount = 0;

RuntimeSettings settings = {
  "",          // wifiSsid
  "",          // wifiPass
  "ntfy.sh",   // ntfyHost
  "",          // ntfyTopic
  "",          // ntfyToken
  "pool.ntp.org",
  true,        // ntfyTls
  120,         // timezoneOffsetMinutes, Europe/Paris summer default
  0.75f,       // confidenceThreshold
  0.12f,       // matchDistanceAtZero
  4.0f,        // triggerMultiplier
  650,         // minTriggerAbs
  800,         // cooldownMs
  1500,        // captureMs
  12,          // calibrationSamples
  false,       // autoNtp
  false,       // autoQueueFlush
};

AdvancedADC adc(kMicPin);
USBHostMSD msd;
mbed::FATFileSystem usb("usb");
mbed::DigitalOut usbHostEnable(PB_8, 1);
WiFiUDP ntpUdp;

bool usbMounted = false;
bool adcStarted = false;
bool wifiConfigured = false;
bool ntpStarted = false;
bool timeSynced = false;
uint32_t epochAtSync = 0;
unsigned long millisAtSync = 0;
unsigned long lastWifiAttemptMs = 0;
unsigned long lastQueueFlushMs = 0;
unsigned long lastStatusPrintMs = 0;

float dcOffset = 32768.0f;
float noiseFloorAbs = 150.0f;
size_t loudSampleCount = 0;
CaptureState captureState = CaptureState::Idle;
uint16_t preRoll[kPreRollSamples];
size_t preRollIndex = 0;
bool preRollFilled = false;
uint16_t captureBuffer[kMaxCaptureSamples];
size_t captureCount = 0;
uint16_t captureNoiseFloor = 0;
unsigned long captureStartedMs = 0;

bool calibrationActive = false;
int calibrationButtonIndex = -1;
uint8_t calibrationTarget = 0;
uint8_t calibrationCount = 0;
float calibrationAccum[kFeatureCount];

uint8_t selectedButtonNumber = 0;
PanelButtonState calibrationPanelButton = {kCalibrationButtonPin, false, false, 0, 0, false};
PanelButtonState nextPanelButton = {kNextButtonPin, false, false, 0, 0, false};
PanelButtonState previousPanelButton = {kPreviousButtonPin, false, false, 0, 0, false};

uint8_t statusBlinkTogglesRemaining = 0;
bool statusBlinkState = false;
bool statusBlinkFinalOn = false;
unsigned long statusBlinkNextToggleMs = 0;
unsigned long statusLedPulseUntilMs = 0;

char serialLine[96];
size_t serialLineLength = 0;

bool isUsbPath(const char *path) {
  return path != nullptr && strncmp(path, "/usb", 4) == 0;
}

bool isUsbReady() {
  return usbMounted && msd.connected();
}

void copyText(char *dest, size_t destSize, const char *src) {
  if (destSize == 0) {
    return;
  }
  if (src == nullptr) {
    dest[0] = '\0';
    return;
  }
  strncpy(dest, src, destSize - 1);
  dest[destSize - 1] = '\0';
}

char *trimInPlace(char *text) {
  if (text == nullptr) {
    return text;
  }

  while (*text && isspace(static_cast<unsigned char>(*text))) {
    text++;
  }

  char *end = text + strlen(text);
  while (end > text && isspace(static_cast<unsigned char>(*(end - 1)))) {
    end--;
  }
  *end = '\0';
  return text;
}

bool parseBoolValue(const char *value, bool defaultValue) {
  if (value == nullptr || value[0] == '\0') {
    return defaultValue;
  }
  return strcmp(value, "1") == 0 ||
         strcasecmp(value, "true") == 0 ||
         strcasecmp(value, "yes") == 0 ||
         strcasecmp(value, "on") == 0;
}

void ensureDirectories() {
  mkdir("/usb/config", 0777);
  mkdir("/usb/templates", 0777);
  mkdir("/usb/logs", 0777);
  mkdir("/usb/queue", 0777);
  mkdir("/usb/captures", 0777);
}

bool mountUsbStick(uint32_t timeoutMs = 15000) {
  if (isUsbReady()) {
    return true;
  }
  if (usbMounted && !msd.connected()) {
    Serial.println("USB stick disconnected; unmounting filesystem.");
    usb.unmount();
    usbMounted = false;
  }

  pinMode(PA_15, OUTPUT);
  digitalWrite(PA_15, HIGH);
  usbHostEnable = 1;

  Serial.println("Waiting for USB stick on USB-A...");
  const unsigned long started = millis();
  while (!msd.connect()) {
    if (millis() - started > timeoutMs) {
      Serial.println("USB stick not found yet.");
      return false;
    }
    delay(100);
  }

  Serial.println("Mounting USB stick as /usb...");
  const int mountResult = usb.mount(&msd);
  if (mountResult != 0) {
    Serial.print("USB mount failed: ");
    Serial.println(mountResult);
    return false;
  }

  usbMounted = true;
  ensureDirectories();
  Serial.println("USB stick mounted.");
  return true;
}

bool fileExists(const char *path) {
  if (isUsbPath(path) && !isUsbReady()) {
    return false;
  }

  FILE *file = fopen(path, "r");
  if (file == nullptr) {
    return false;
  }
  fclose(file);
  return true;
}

void loadDefaultButtons() {
  const char *defaults[][3] = {
    {"A1", "manger", "Manger"},
    {"A2", "eau", "Eau"},
    {"A3", "jouer", "Jouer"},
    {"A4", "dehors", "Dehors"},
    {"B1", "dedans", "Dedans"},
    {"B2", "calin", "Calin"},
  };

  buttonCount = sizeof(defaults) / sizeof(defaults[0]);
  for (size_t i = 0; i < buttonCount; i++) {
    copyText(buttons[i].slot, sizeof(buttons[i].slot), defaults[i][0]);
    copyText(buttons[i].word, sizeof(buttons[i].word), defaults[i][1]);
    copyText(buttons[i].ntfyLabel, sizeof(buttons[i].ntfyLabel), defaults[i][2]);
    buttons[i].templateLoaded = false;
    buttons[i].templateSamples = 0;
    buttons[i].lastRecognizedMs = 0;
    memset(buttons[i].templ, 0, sizeof(buttons[i].templ));
  }
}

bool loadButtons() {
  loadDefaultButtons();

  if (!mountUsbStick(1000)) {
    Serial.println("Using compiled default buttons: USB not mounted.");
    return false;
  }

  FILE *file = fopen(kButtonsPath, "r");
  if (file == nullptr) {
    Serial.println("Using compiled default buttons: /usb/config/buttons.csv missing.");
    return false;
  }

  char line[160];
  bool firstLine = true;
  size_t loaded = 0;
  while (fgets(line, sizeof(line), file) != nullptr && loaded < kMaxButtons) {
    char *row = trimInPlace(line);
    if (row[0] == '\0' || row[0] == '#') {
      continue;
    }
    if (firstLine && strstr(row, "slot") != nullptr) {
      firstLine = false;
      continue;
    }
    firstLine = false;

    char *slot = trimInPlace(strtok(row, ","));
    char *word = trimInPlace(strtok(nullptr, ","));
    char *label = trimInPlace(strtok(nullptr, "\r\n"));
    if (slot == nullptr || word == nullptr || slot[0] == '\0' || word[0] == '\0') {
      continue;
    }
    if (label == nullptr || label[0] == '\0') {
      label = word;
    }

    ButtonConfig &button = buttons[loaded];
    copyText(button.slot, sizeof(button.slot), slot);
    copyText(button.word, sizeof(button.word), word);
    copyText(button.ntfyLabel, sizeof(button.ntfyLabel), label);
    button.templateLoaded = false;
    button.templateSamples = 0;
    button.lastRecognizedMs = 0;
    memset(button.templ, 0, sizeof(button.templ));
    loaded++;
  }

  fclose(file);

  if (loaded > 0) {
    buttonCount = loaded;
  }

  Serial.print("Loaded buttons: ");
  Serial.println(buttonCount);
  return loaded > 0;
}

void applyIniValue(const char *key, const char *value, const bool secretsFile) {
  if (strcmp(key, "wifi_ssid") == 0) {
    copyText(settings.wifiSsid, sizeof(settings.wifiSsid), value);
  } else if (strcmp(key, "wifi_pass") == 0) {
    copyText(settings.wifiPass, sizeof(settings.wifiPass), value);
  } else if (strcmp(key, "ntfy_host") == 0) {
    copyText(settings.ntfyHost, sizeof(settings.ntfyHost), value);
  } else if (strcmp(key, "ntfy_topic") == 0) {
    copyText(settings.ntfyTopic, sizeof(settings.ntfyTopic), value);
  } else if (strcmp(key, "ntfy_token") == 0) {
    copyText(settings.ntfyToken, sizeof(settings.ntfyToken), value);
  } else if (strcmp(key, "ntfy_tls") == 0) {
    settings.ntfyTls = parseBoolValue(value, true);
  } else if (strcmp(key, "ntp_host") == 0) {
    copyText(settings.ntpHost, sizeof(settings.ntpHost), value);
  } else if (strcmp(key, "timezone_offset_minutes") == 0) {
    settings.timezoneOffsetMinutes = atoi(value);
  } else if (strcmp(key, "confidence_threshold") == 0 && !secretsFile) {
    settings.confidenceThreshold = atof(value);
  } else if (strcmp(key, "match_distance_at_zero") == 0 && !secretsFile) {
    settings.matchDistanceAtZero = atof(value);
  } else if (strcmp(key, "trigger_multiplier") == 0 && !secretsFile) {
    settings.triggerMultiplier = atof(value);
  } else if (strcmp(key, "min_trigger_abs") == 0 && !secretsFile) {
    settings.minTriggerAbs = static_cast<uint16_t>(atoi(value));
  } else if (strcmp(key, "cooldown_ms") == 0 && !secretsFile) {
    settings.cooldownMs = static_cast<uint16_t>(atoi(value));
  } else if (strcmp(key, "capture_ms") == 0 && !secretsFile) {
    const uint16_t requested = static_cast<uint16_t>(atoi(value));
    settings.captureMs = requested > kMaxCaptureMs ? kMaxCaptureMs : requested;
  } else if (strcmp(key, "calibration_samples") == 0 && !secretsFile) {
    const int requested = atoi(value);
    if (requested >= 3 && requested <= 30) {
      settings.calibrationSamples = static_cast<uint8_t>(requested);
    }
  } else if (strcmp(key, "auto_ntp") == 0 && !secretsFile) {
    settings.autoNtp = parseBoolValue(value, false);
  } else if (strcmp(key, "auto_queue_flush") == 0 && !secretsFile) {
    settings.autoQueueFlush = parseBoolValue(value, false);
  }
}

bool loadIniFile(const char *path, bool secretsFile) {
  if (!mountUsbStick(1000)) {
    return false;
  }

  FILE *file = fopen(path, "r");
  if (file == nullptr) {
    Serial.print("Config missing: ");
    Serial.println(path);
    return false;
  }

  char line[180];
  while (fgets(line, sizeof(line), file) != nullptr) {
    char *row = trimInPlace(line);
    if (row[0] == '\0' || row[0] == '#' || row[0] == ';') {
      continue;
    }

    char *equals = strchr(row, '=');
    if (equals == nullptr) {
      continue;
    }

    *equals = '\0';
    char *key = trimInPlace(row);
    char *value = trimInPlace(equals + 1);
    applyIniValue(key, value, secretsFile);
  }

  fclose(file);
  return true;
}

void loadRuntimeConfig() {
  loadIniFile(kSecretsPath, true);
  loadIniFile(kSettingsPath, false);
  wifiConfigured = settings.wifiSsid[0] != '\0' && settings.ntfyTopic[0] != '\0';

  Serial.print("Wi-Fi config: ");
  Serial.println(wifiConfigured ? "ready" : "missing SSID or ntfy topic");
  Serial.print("Capture window ms: ");
  Serial.println(settings.captureMs);
  Serial.print("Confidence threshold: ");
  Serial.println(settings.confidenceThreshold, 2);
  Serial.print("Auto NTP: ");
  Serial.println(settings.autoNtp ? "on" : "off");
  Serial.print("Auto queue flush: ");
  Serial.println(settings.autoQueueFlush ? "on" : "off");
}

void templatePathForButton(const ButtonConfig &button, char *path, size_t pathSize) {
  snprintf(path, pathSize, "/usb/templates/%s.tpl", button.slot);
}

bool parseFeaturesLine(char *value, float *features) {
  for (uint8_t i = 0; i < kFeatureCount; i++) {
    char *token = (i == 0) ? strtok(value, ",") : strtok(nullptr, ",");
    if (token == nullptr) {
      return false;
    }
    features[i] = atof(trimInPlace(token));
  }
  return true;
}

bool loadTemplate(ButtonConfig &button) {
  if (!isUsbReady()) {
    return false;
  }

  char path[80];
  templatePathForButton(button, path, sizeof(path));
  FILE *file = fopen(path, "r");
  if (file == nullptr) {
    button.templateLoaded = false;
    return false;
  }

  bool foundFeatures = false;
  char line[220];
  while (fgets(line, sizeof(line), file) != nullptr) {
    char *row = trimInPlace(line);
    char *equals = strchr(row, '=');
    if (equals == nullptr) {
      continue;
    }
    *equals = '\0';
    char *key = trimInPlace(row);
    char *value = trimInPlace(equals + 1);
    if (strcmp(key, "samples") == 0) {
      button.templateSamples = static_cast<uint16_t>(atoi(value));
    } else if (strcmp(key, "features") == 0) {
      foundFeatures = parseFeaturesLine(value, button.templ);
    }
  }

  fclose(file);
  button.templateLoaded = foundFeatures;
  return foundFeatures;
}

void loadTemplates() {
  uint8_t loaded = 0;
  for (size_t i = 0; i < buttonCount; i++) {
    if (loadTemplate(buttons[i])) {
      loaded++;
    }
  }

  Serial.print("Loaded templates: ");
  Serial.print(loaded);
  Serial.print("/");
  Serial.println(buttonCount);
}

bool saveTemplate(ButtonConfig &button, const float *features, uint16_t sampleCount) {
  if (!mountUsbStick(3000)) {
    return false;
  }

  char path[80];
  templatePathForButton(button, path, sizeof(path));
  FILE *file = fopen(path, "w");
  if (file == nullptr) {
    Serial.print("Template save failed: ");
    Serial.println(path);
    return false;
  }

  fprintf(file, "TPB_TEMPLATE_V1\n");
  fprintf(file, "slot=%s\n", button.slot);
  fprintf(file, "word=%s\n", button.word);
  fprintf(file, "samples=%u\n", sampleCount);
  fprintf(file, "features=");
  for (uint8_t i = 0; i < kFeatureCount; i++) {
    if (i > 0) {
      fputc(',', file);
    }
    fprintf(file, "%.7f", features[i]);
    button.templ[i] = features[i];
  }
  fputc('\n', file);
  fclose(file);

  button.templateLoaded = true;
  button.templateSamples = sampleCount;
  Serial.print("Saved template: ");
  Serial.println(path);
  return true;
}

void printButtonList() {
  Serial.println("Buttons:");
  for (size_t i = 0; i < buttonCount; i++) {
    Serial.print("  ");
    Serial.print(buttons[i].slot);
    Serial.print(" -> ");
    Serial.print(buttons[i].word);
    Serial.print(" / ");
    Serial.print(buttons[i].ntfyLabel);
    Serial.print(" / template=");
    Serial.println(buttons[i].templateLoaded ? "yes" : "no");
  }
}

int findButtonBySlot(const char *slot) {
  for (size_t i = 0; i < buttonCount; i++) {
    if (strcasecmp(buttons[i].slot, slot) == 0) {
      return static_cast<int>(i);
    }
  }
  return -1;
}

size_t selectableButtonCount() {
  return buttonCount < kMaxPanelSelection ? buttonCount : kMaxPanelSelection;
}

int selectedButtonIndex() {
  if (selectedButtonNumber == 0 || selectedButtonNumber > selectableButtonCount()) {
    return -1;
  }
  return static_cast<int>(selectedButtonNumber - 1);
}

void setStatusLed(bool on) {
  digitalWrite(LED_BUILTIN, on ? kStatusLedOn : kStatusLedOff);
}

void stopStatusLedEffects() {
  statusBlinkTogglesRemaining = 0;
  statusLedPulseUntilMs = 0;
  setStatusLed(calibrationActive);
}

void startStatusBlink(uint8_t flashes, bool finalOn) {
  statusBlinkTogglesRemaining = flashes * 2;
  statusBlinkState = false;
  statusBlinkFinalOn = finalOn;
  statusBlinkNextToggleMs = millis();
  statusLedPulseUntilMs = 0;
  setStatusLed(false);
}

void pulseStatusLed() {
  if (calibrationActive && statusBlinkTogglesRemaining == 0) {
    statusLedPulseUntilMs = millis() + kStatusPulseMs;
  }
}

void updateStatusLed() {
  const unsigned long now = millis();
  if (statusBlinkTogglesRemaining > 0) {
    if (now >= statusBlinkNextToggleMs) {
      statusBlinkState = !statusBlinkState;
      setStatusLed(statusBlinkState);
      statusBlinkTogglesRemaining--;
      statusBlinkNextToggleMs = now + kStatusBlinkMs;
      if (statusBlinkTogglesRemaining == 0) {
        setStatusLed(statusBlinkFinalOn);
      }
    }
    return;
  }

  if (statusLedPulseUntilMs > 0) {
    if (now < statusLedPulseUntilMs) {
      setStatusLed(false);
      return;
    }
    statusLedPulseUntilMs = 0;
  }

  setStatusLed(calibrationActive);
}

void writeBinaryLeds(uint8_t value) {
  for (uint8_t i = 0; i < kBinaryLedCount; i++) {
    digitalWrite(kBinaryLedPins[i], (value & (1U << i)) ? HIGH : LOW);
  }
}

void updateBinaryLeds() {
  const uint8_t value = selectedButtonNumber <= kMaxPanelSelection ? selectedButtonNumber : 0;
  writeBinaryLeds(value);
}

void printPanelSelection() {
  const int index = selectedButtonIndex();
  Serial.print("Panel selection: ");
  if (index < 0) {
    Serial.println("none (0)");
    return;
  }

  Serial.print(selectedButtonNumber);
  Serial.print(" -> ");
  Serial.print(buttons[index].slot);
  Serial.print(" / ");
  Serial.println(buttons[index].word);
}

void setPanelSelection(uint8_t number, bool announce = false) {
  const size_t maxSelection = selectableButtonCount();
  if (number > maxSelection) {
    number = static_cast<uint8_t>(maxSelection);
  }
  selectedButtonNumber = number;
  updateBinaryLeds();
  if (announce) {
    printPanelSelection();
  }
}

void syncPanelSelectionToButtonIndex(int index) {
  if (index >= 0 && static_cast<size_t>(index) < selectableButtonCount()) {
    setPanelSelection(static_cast<uint8_t>(index + 1));
  } else {
    setPanelSelection(0);
  }
}

void clampPanelSelection() {
  if (selectedButtonNumber > selectableButtonCount()) {
    setPanelSelection(0);
  } else {
    updateBinaryLeds();
  }
}

void stepPanelSelection(int delta) {
  if (calibrationActive) {
    return;
  }

  const int maxSelection = static_cast<int>(selectableButtonCount());
  int next = static_cast<int>(selectedButtonNumber) + delta;
  if (next < 0) {
    next = 0;
  } else if (next > maxSelection) {
    next = maxSelection;
  }

  if (next != selectedButtonNumber) {
    setPanelSelection(static_cast<uint8_t>(next), true);
  }
}

void selectAfterCompletedCalibration(int completedIndex) {
  const size_t maxSelection = selectableButtonCount();
  const uint8_t next = (completedIndex >= 0 && static_cast<size_t>(completedIndex + 1) < maxSelection)
                         ? static_cast<uint8_t>(completedIndex + 2)
                         : 0;
  setPanelSelection(next, true);
}

void cancelCalibration(const char *message) {
  calibrationActive = false;
  calibrationButtonIndex = -1;
  calibrationTarget = 0;
  calibrationCount = 0;
  stopStatusLedEffects();
  if (message != nullptr) {
    Serial.println(message);
  }
}

uint16_t captureTargetSamples() {
  const uint32_t requested = (static_cast<uint32_t>(settings.captureMs) * kSampleRate) / 1000;
  if (requested == 0 || requested > kMaxCaptureSamples) {
    return kMaxCaptureSamples;
  }
  return static_cast<uint16_t>(requested);
}

float triggerThreshold() {
  const float adaptive = noiseFloorAbs * settings.triggerMultiplier;
  return adaptive > settings.minTriggerAbs ? adaptive : settings.minTriggerAbs;
}

void rememberPreRoll(uint16_t sample) {
  preRoll[preRollIndex] = sample;
  preRollIndex = (preRollIndex + 1) % kPreRollSamples;
  if (preRollIndex == 0) {
    preRollFilled = true;
  }
}
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
void loop() {
  pollAudio();
  pollSerial();
  pollControlPanel();
  periodicNetworkWork();
  periodicStatusPrint();
  updateStatusLed();
}

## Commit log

2026-06-20 Un autre setup pour les boutons : micro captant le son des boutons + interprétation (avec boutons enregistreurs/émetteurs achetés dans le commerce)
    [button-riser.scad, button-riser.stl, buttons.csv]
2026-06-20 Support de bouton : le bouton repose sur une protubérance intérieure de l'anneau
    [button-riser.scad, button-riser.stl]
2026-06-20 Fix les accents
2026-06-22 Schéma de branchement global
2026-06-30 Explications de setup
2026-06-30 Ajoute le panneau de calibration physique
2026-06-30 Ajoute la commande `select 0` par moniteur série
2026-06-30 Ajoute la commande `ledtest 0` par moniteur série
2026-06-30 Changer les mots
    [buttons.csv]
2026-06-30 Ajoute des commandes pour débugger le crash (usb semble avoir un problème) et disable l'auto-connexion
    [main.cpp]
